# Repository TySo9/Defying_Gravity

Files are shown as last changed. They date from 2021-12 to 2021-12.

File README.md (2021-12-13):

# Defying_Gravity
Repository for University Kentucky Senior Capstone Design Team (Spring/Fall 2021), Defying Gravity.

## iOS App
  - Written in C# for potential multi-platform support in the future
  - Designed for iPad
  - Controls the ESP32 via Wi-Fi
  
## ESP32
  - Written in Arduino C
  - Controls motors, sensors, etc on the platform
  - Controlled by iOS App via Wi-Fi

## 3D Drawings
  - Files for the 3D printed parts of the device
     - Left Brake "Pads"
     - Right Brake "Pads"
     - Washer (?)

## 3D Drawings (KiCAD)
  - Files for PCB

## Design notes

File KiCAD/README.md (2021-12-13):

PCB Design Files for KiCAD

Because we decided to build a perfboard based on the Schematic for time, testing, and budget purposes, the PCB itself is unfinished. The Schematic, Ratnest, Part Selection, Footprint Design/Selection, etc.. is all finished. Since all the groundwork is complete, all the next person has to do is move around the footprints, connect the ratnest, and generate Gerbers. Should be quick and easy. I recommend using PCBWay to fabricate the boards.

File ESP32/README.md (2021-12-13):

To upload the code to an ESP32 using Arduino IDE, follow these instructions:
    https://randomnerdtutorials.com/installing-the-esp32-board-in-arduino-ide-windows-instructions/
    
    - Because Arduino does not know how to deal with nested folders, make sure all .h and .cpp library files you are using are put inside the same folder as the            main sketch Defying_Gravity_Main.ino
    
To upload the code to an ESP32 using Visual Studio Code, follow these instructions:
    https://randomnerdtutorials.com/vs-code-platformio-ide-esp32-esp8266-arduino/

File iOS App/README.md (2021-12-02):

At the current moment, I don't know how to add upload the code effectively to this but link to the gitbub with the code: https://github.com/lroberts7952/SlipNTrip

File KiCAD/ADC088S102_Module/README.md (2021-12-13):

PCB Design for an ADC module, can be used to attach to breakboard or perfbpard

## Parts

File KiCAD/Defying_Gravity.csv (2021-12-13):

Reference | Value | Footprint | Datasheet | MANUFACTURER | PARTREV
U1 | ESP32-DEVKITC-32D | _Defying_Gravity_Parts:MODULE_ESP32-DEVKITC-32D | https://www.espressif.com/sites/default/files/documentation/esp32-wroom-32_datasheet_en.pdf | Espressif Systems | 4
J4 | E-STOP (inverted) |  | ~
J5 | BRAKES POWER |  | ~
J3 | BUCK CONVERTER |  | ~
R12 | 0 Ω | Resistor_SMD:R_0805_2012Metric_Pad1.20x1.40mm_HandSolder | ~
R11 | 0 Ω | Resistor_SMD:R_0805_2012Metric_Pad1.20x1.40mm_HandSolder | ~
J12 | VESC 2 |  | ~
J11 | VESC 1 |  | ~
D1 | 1N5408 | Diode_THT:D_DO-201AD_P15.24mm_Horizontal | http://www.vishay.com/docs/88516/1n5400.pdf
Q1 | IRLB8721PBF | Package_TO_SOT_THT:TO-220-3_Vertical | http://www.infineon.com/dgdl/irlb8721pbf.pdf?fileId=5546d462533600a40153566056732591
C22 | 0.1 uF | Capacitor_SMD:C_0805_2012Metric_Pad1.18x1.45mm_HandSolder | ~
R3 | 51Ω | Resistor_SMD:R_0805_2012Metric_Pad1.20x1.40mm_HandSolder | ~
C12 | 1 uF | Capacitor_SMD:C_0805_2012Metric_Pad1.18x1.45mm_HandSolder | ~
R13 | 0 Ω | Resistor_SMD:R_0805_2012Metric_Pad1.20x1.40mm_HandSolder | ~
U2 | LP2950-3.0_TO92 | Package_TO_SOT_THT:TO-92_Inline | http://www.ti.com/lit/ds/symlink/lp2950-n.pdf
C11 | 1 uF | Capacitor_SMD:C_0805_2012Metric_Pad1.18x1.45mm_HandSolder | ~
C21 | 0.1 uF | Capacitor_SMD:C_0805_2012Metric_Pad1.18x1.45mm_HandSolder | ~
C4 | 1 uF | Capacitor_SMD:C_0805_2012Metric_Pad1.18x1.45mm_HandSolder | ~
C23 | 0.1 uF | Capacitor_SMD:C_0805_2012Metric_Pad1.18x1.45mm_HandSolder | ~
C312 | 1nF | Capacitor_SMD:C_0805_2012Metric_Pad1.18x1.45mm_HandSolder | ~
R212 | 22Ω | Resistor_SMD:R_0805_2012Metric_Pad1.20x1.40mm_HandSolder | ~
C313 | 1nF | Capacitor_SMD:C_0805_2012Metric_Pad1.18x1.45mm_HandSolder | ~
R213 | 22Ω | Resistor_SMD:R_0805_2012Metric_Pad1.20x1.40mm_HandSolder | ~
J22 | PRESSURE SENSOR GRID | _Defying_Gravity_Parts:M50-3550642 | ~
C314 | 1nF | Capacitor_SMD:C_0805_2012Metric_Pad1.18x1.45mm_HandSolder | ~
R214 | 22Ω | Resistor_SMD:R_0805_2012Metric_Pad1.20x1.40mm_HandSolder | ~
C315 | 1nF | Capacitor_SMD:C_0805_2012Metric_Pad1.18x1.45mm_HandSolder | ~
R215 | 22Ω | Resistor_SMD:R_0805_2012Metric_Pad1.20x1.40mm_HandSolder | ~
C316 | 1nF | Capacitor_SMD:C_0805_2012Metric_Pad1.18x1.45mm_HandSolder | ~
R216 | 22Ω | Resistor_SMD:R_0805_2012Metric_Pad1.20x1.40mm_HandSolder | ~
C317 | 1nF | Capacitor_SMD:C_0805_2012Metric_Pad1.18x1.45mm_HandSolder | ~
R217 | 22Ω | Resistor_SMD:R_0805_2012Metric_Pad1.20x1.40mm_HandSolder | ~
C318 | 1nF | Capacitor_SMD:C_0805_2012Metric_Pad1.18x1.45mm_HandSolder | ~
R218 | 22Ω | Resistor_SMD:R_0805_2012Metric_Pad1.20x1.40mm_HandSolder | ~
C319 | 1nF | Capacitor_SMD:C_0805_2012Metric_Pad1.18x1.45mm_HandSolder | ~
R219 | 22Ω | Resistor_SMD:R_0805_2012Metric_Pad1.20x1.40mm_HandSolder | ~
C320 | 1nF | Capacitor_SMD:C_0805_2012Metric_Pad1.18x1.45mm_HandSolder | ~
R220 | 22Ω | Resistor_SMD:R_0805_2012Metric_Pad1.20x1.40mm_HandSolder | ~
C321 | 1nF | Capacitor_SMD:C_0805_2012Metric_Pad1.18x1.45mm_HandSolder | ~
R221 | 22Ω | Resistor_SMD:R_0805_2012Metric_Pad1.20x1.40mm_HandSolder | ~
C322 | 1nF | Capacitor_SMD:C_0805_2012Metric_Pad1.18x1.45mm_HandSolder | ~
R222 | 22Ω | Resistor_SMD:R_0805_2012Metric_Pad1.20x1.40mm_HandSolder | ~
C31 | 1nF | Capacitor_SMD:C_0805_2012Metric_Pad1.18x1.45mm_HandSolder | ~
C32 | 1nF | Capacitor_SMD:C_0805_2012Metric_Pad1.18x1.45mm_HandSolder | ~
J21 | PRESSURE SENSOR GIRD w/ power | _Defying_Gravity_Parts:M50-3550642 | ~
C33 | 1nF | Capacitor_SMD:C_0805_2012Metric_Pad1.18x1.45mm_HandSolder | ~
R23 | 22Ω | Resistor_SMD:R_0805_2012Metric_Pad1.20x1.40mm_HandSolder | ~
C34 | 1nF | Capacitor_SMD:C_0805_2012Metric_Pad1.18x1.45mm_HandSolder | ~
R24 | 22Ω | Resistor_SMD:R_0805_2012Metric_Pad1.20x1.40mm_HandSolder | ~
C35 | 1nF | Capacitor_SMD:C_0805_2012Metric_Pad1.18x1.45mm_HandSolder | ~
R25 | 22Ω | Resistor_SMD:R_0805_2012Metric_Pad1.20x1.40mm_HandSolder | ~
C36 | 1nF | Capacitor_SMD:C_0805_2012Metric_Pad1.18x1.45mm_HandSolder | ~
R26 | 22Ω | Resistor_SMD:R_0805_2012Metric_Pad1.20x1.40mm_HandSolder | ~
C37 | 1nF | Capacitor_SMD:C_0805_2012Metric_Pad1.18x1.45mm_HandSolder | ~
R27 | 22Ω | Resistor_SMD:R_0805_2012Metric_Pad1.20x1.40mm_HandSolder | ~
C38 | 1nF | Capacitor_SMD:C_0805_2012Metric_Pad1.18x1.45mm_HandSolder | ~
R28 | 22Ω | Resistor_SMD:R_0805_2012Metric_Pad1.20x1.40mm_HandSolder | ~
C39 | 1nF | Capacitor_SMD:C_0805_2012Metric_Pad1.18x1.45mm_HandSolder | ~
R29 | 22Ω | Resistor_SMD:R_0805_2012Metric_Pad1.20x1.40mm_HandSolder | ~
C310 | 1nF | Capacitor_SMD:C_0805_2012Metric_Pad1.18x1.45mm_HandSolder | ~
R210 | 22Ω | Resistor_SMD:R_0805_2012Metric_Pad1.20x1.40mm_HandSolder | ~
C311 | 1nF | Capacitor_SMD:C_0805_2012Metric_Pad1.18x1.45mm_HandSolder | ~
R211 | 22Ω | Resistor_SMD:R_0805_2012Metric_Pad1.20x1.40mm_HandSolder | ~
R22 | 22Ω | Resistor_SMD:R_0805_2012Metric_Pad1.20x1.40mm_HandSolder | ~
R21 | 22Ω | Resistor_SMD:R_0805_2012Metric_Pad1.20x1.40mm_HandSolder | ~
U33 | ADC088S102CIMT_NOPB | _Defying_Gravity_Parts:ADC088S102CIMT&slash_NOPB | https://www.ti.com/lit/ds/symlink/adc088s102.pdf?HQS=dis-mous-null-mousermode-dsf-pf-null-wwe&ts=1635440733857
U32 | ADC088S102CIMT_NOPB | _Defying_Gravity_Parts:ADC088S102CIMT&slash_NOPB | https://www.ti.com/lit/ds/symlink/adc088s102.pdf?HQS=dis-mous-null-mousermode-dsf-pf-null-wwe&ts=1635440733857
U31 | ADC088S102CIMT_NOPB | _Defying_Gravity_Parts:ADC088S102CIMT&slash_NOPB | https://www.ti.com/lit/ds/symlink/adc088s102.pdf?HQS=dis-mous-null-mousermode-dsf-pf-null-wwe&ts=1635440733857

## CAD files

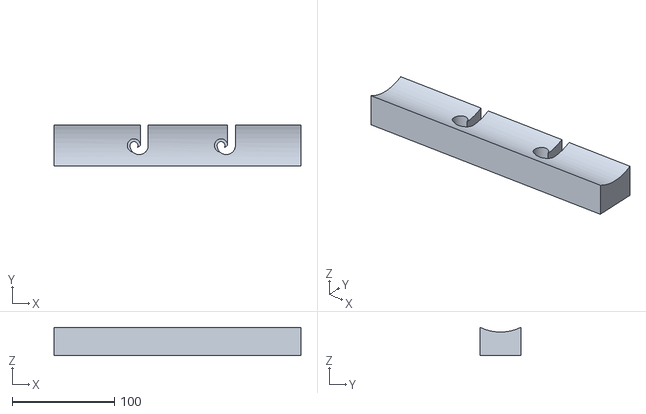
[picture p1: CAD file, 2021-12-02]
3D Drawings/Left Brake Pad (1).stl
241.3 x 40.0 x 27.8

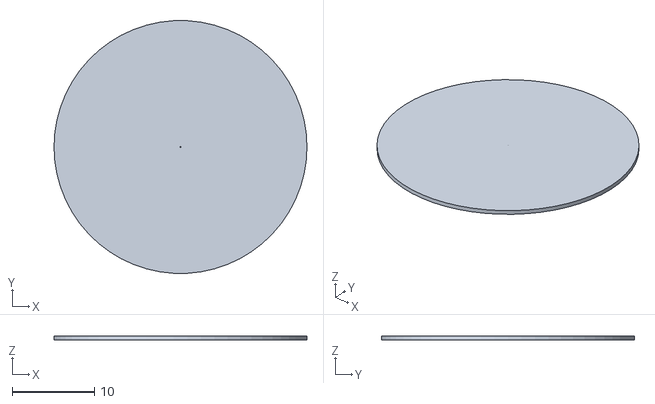
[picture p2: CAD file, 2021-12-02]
3D Drawings/Washer (1).stl
30.8 x 30.8 x 0.5

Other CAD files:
3D Drawings/Right Brake Pad.stl

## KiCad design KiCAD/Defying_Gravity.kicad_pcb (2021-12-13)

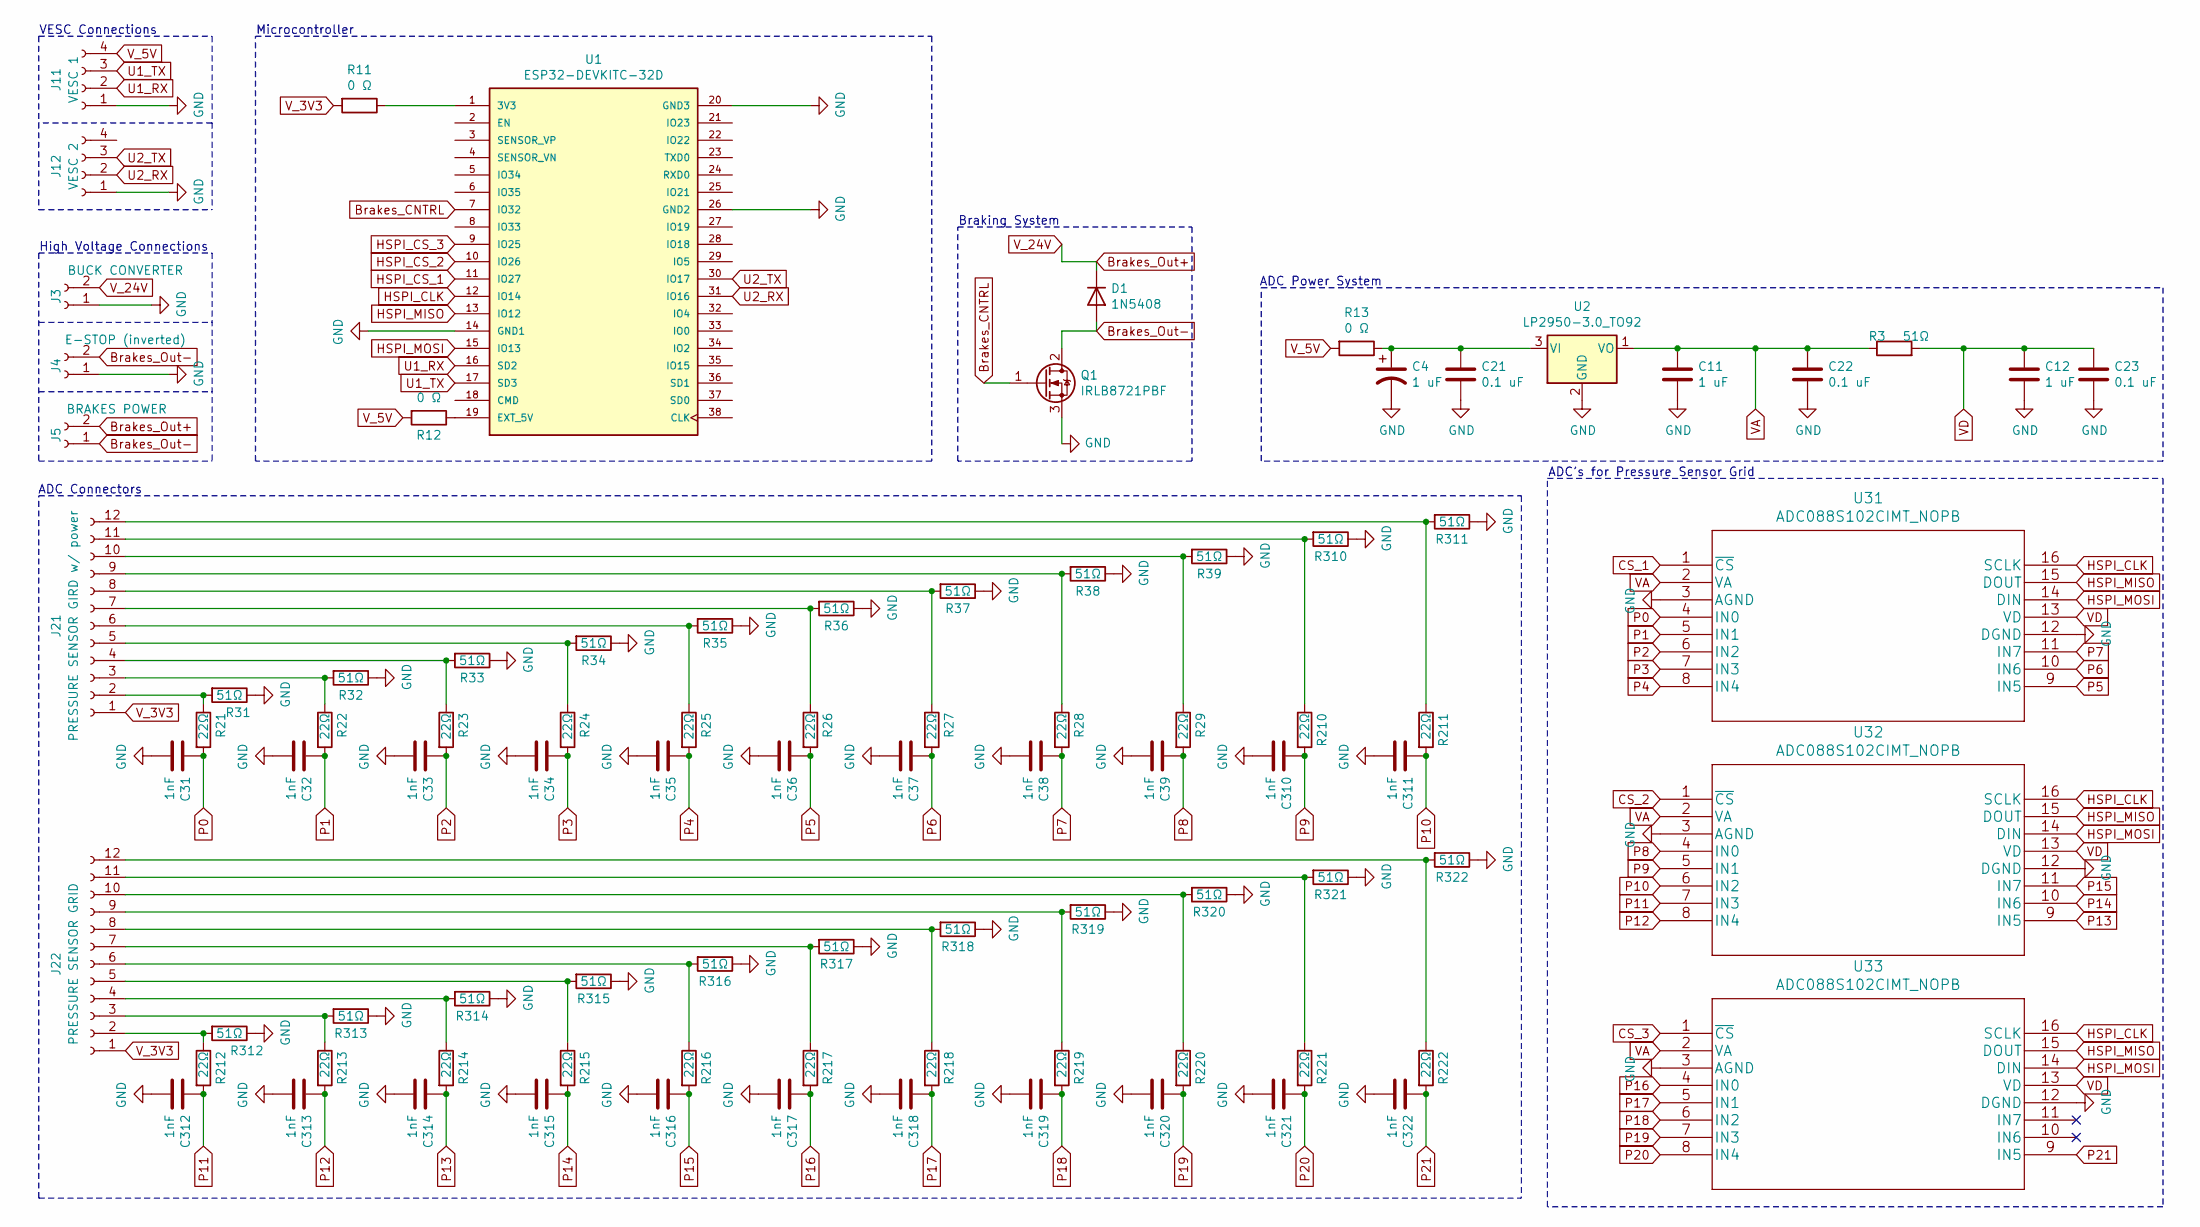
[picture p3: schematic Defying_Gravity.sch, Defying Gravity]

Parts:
C4, C11, C12: 1 uF; C_0805_2012Metric_Pad1.18x1.45mm_HandSolder
C21, C22, C23: 0.1 uF; C_0805_2012Metric_Pad1.18x1.45mm_HandSolder
C31, C32, C33, C34, C35, C36, C37, C38, C39, C310, C311, C312, C313, C314, C315, C316, C317, C318, C319, C320, C321, C322: 1nF; C_0805_2012Metric_Pad1.18x1.45mm_HandSolder
D1: 1N5408; D_DO-201AD_P15.24mm_Horizontal
J3: BUCK CONVERTER; TerminalBlock_Altech_AK300-2_P5.00mm
J4: E-STOP (inverted); TerminalBlock_Altech_AK300-2_P5.00mm
J5: BRAKES POWER; TerminalBlock_Altech_AK300-2_P5.00mm
J11: VESC 1; PinHeader_1x04_P2.54mm_Vertical
J12: VESC 2; PinHeader_1x04_P2.54mm_Vertical
J21: PRESSURE SENSOR GIRD w/ power; M50-3550642
J22: PRESSURE SENSOR GRID; M50-3550642
Q1: IRLB8721PBF; TO-220-3_Vertical
R3, R31, R32, R33, R34, R35, R36, R37, R38, R39, R310, R311, R312, R313, R314, R315, R316, R317, R318, R319, R320, R321, R322: 51Ω; R_0805_2012Metric_Pad1.20x1.40mm_HandSolder
R11, R12, R13: 0 Ω; R_0805_2012Metric_Pad1.20x1.40mm_HandSolder
R21, R22, R23, R24, R25, R26, R27, R28, R29, R210, R211, R212, R213, R214, R215, R216, R217, R218, R219, R220, R221, R222: 22Ω; R_0805_2012Metric_Pad1.20x1.40mm_HandSolder
U1: ESP32-DEVKITC-32D; MODULE_ESP32-DEVKITC-32D; PARTREV 4
U2: LP2950-3.0_TO92; TO-92_Inline
U31, U32, U33: ADC088S102CIMT_NOPB; ADC088S102CIMT&slash_NOPB

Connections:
Brakes_CNTRL: Q1.1 (G), U1.7 (IO32)
Brakes_Out+: D1.1 (K), J3.2, J5.2
Brakes_Out-: D1.2 (A), J4.2, J5.1, Q1.2 (D)
CS_1: U31.1 (~CS)
CS_2: U32.1 (~CS)
CS_3: U33.1 (~CS)
GND: C4.2, C11.2, C12.2, C21.2, C22.2, C23.2, C31.2, C32.2, C33.2, C34.2, C35.2, C36.2, C37.2, C38.2, C39.2, C310.2, C311.2, C312.2, C313.2, C314.2, C315.2, C316.2, C317.2, C318.2, C319.2, C320.2, C321.2, C322.2, J3.1, J4.1, J11.1, J12.1, Q1.3 (S), R31.1, R32.1, R33.1, R34.1, R35.1, R36.1, R37.1, R38.1, R39.1, R310.1, R311.1, R312.1, R313.1, R314.1, R315.1, R316.1, R317.1, R318.1, R319.1, R320.1, R321.1, R322.1, U1.14 (GND1), U1.20 (GND3), U1.26 (GND2), U2.2 (GND), U31.3 (AGND), U31.12 (DGND), U32.3 (AGND), U32.12 (DGND), U33.3 (AGND), U33.12 (DGND)
HSPI_CLK: U1.12 (IO14), U31.16 (SCLK), U32.16 (SCLK), U33.16 (SCLK)
HSPI_CS_1: U1.11 (IO27)
HSPI_CS_2: U1.10 (IO26)
HSPI_CS_3: U1.9 (IO25)
HSPI_MISO: U1.13 (IO12), U31.15 (DOUT), U32.15 (DOUT), U33.15 (DOUT)
HSPI_MOSI: U1.15 (IO13), U31.14 (DIN), U32.14 (DIN), U33.14 (DIN)
unnamed: C4.1, C21.1, R13.1, U2.3 (VI)
unnamed: J21.2, R21.1, R31.2
unnamed: J21.3, R22.1, R32.2
unnamed: J21.4, R23.1, R33.2
unnamed: J21.5, R24.1, R34.2
unnamed: J21.6, R25.1, R35.2
unnamed: J21.7, R26.1, R36.2
unnamed: J21.8, R27.1, R37.2
unnamed: J21.9, R28.1, R38.2
unnamed: J21.10, R29.1, R39.2
unnamed: J21.11, R210.1, R310.2
unnamed: J21.12, R211.1, R311.2
unnamed: J22.2, R212.1, R312.2
unnamed: J22.3, R213.1, R313.2
unnamed: J22.4, R214.1, R314.2
unnamed: J22.5, R215.1, R315.2
unnamed: J22.6, R216.1, R316.2
unnamed: J22.7, R217.1, R317.2
unnamed: J22.8, R218.1, R318.2
unnamed: J22.9, R219.1, R319.2
unnamed: J22.10, R220.1, R320.2
unnamed: J22.11, R221.1, R321.2
unnamed: J22.12, R222.1, R322.2
unnamed: R11.1, U1.1 (3V3)
unnamed: R12.1, U1.19 (EXT_5V)
P0: C31.1, R21.2, U31.4 (IN0)
P1: C32.1, R22.2, U31.5 (IN1)
P2: C33.1, R23.2, U31.6 (IN2)
P3: C34.1, R24.2, U31.7 (IN3)
P4: C35.1, R25.2, U31.8 (IN4)
P5: C36.1, R26.2, U31.9 (IN5)
P6: C37.1, R27.2, U31.10 (IN6)
P7: C38.1, R28.2, U31.11 (IN7)
P8: C39.1, R29.2, U32.4 (IN0)
P9: C310.1, R210.2, U32.5 (IN1)
P10: C311.1, R211.2, U32.6 (IN2)
P11: C312.1, R212.2, U32.7 (IN3)
P12: C313.1, R213.2, U32.8 (IN4)
P13: C314.1, R214.2, U32.9 (IN5)
P14: C315.1, R215.2, U32.10 (IN6)
P15: C316.1, R216.2, U32.11 (IN7)
P16: C317.1, R217.2, U33.4 (IN0)
P17: C318.1, R218.2, U33.5 (IN1)
P18: C319.1, R219.2, U33.6 (IN2)
P19: C320.1, R220.2, U33.7 (IN3)
P20: C321.1, R221.2, U33.8 (IN4)
P21: C322.1, R222.2, U33.9 (IN5)
U1_RX: J11.2, U1.16 (SD2)
U1_TX: J11.3, U1.17 (SD3)
U2_RX: J12.2, U1.31 (IO16)
U2_TX: J12.3, U1.30 (IO17)
VA: C11.1, C22.1, R3.1, U2.1 (VO), U31.2 (VA), U32.2 (VA), U33.2 (VA)
VD: C12.1, C23.1, R3.2, U31.13 (VD), U32.13 (VD), U33.13 (VD)
V_3V3: J21.1, J22.1, R11.2
V_5V: J11.4, R12.2, R13.2

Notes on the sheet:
VESC Connections
Microcontroller
High Voltage Connections
Braking System
ADC Power System
ADC Connectors
ADC’s for Pressure Sensor Grid

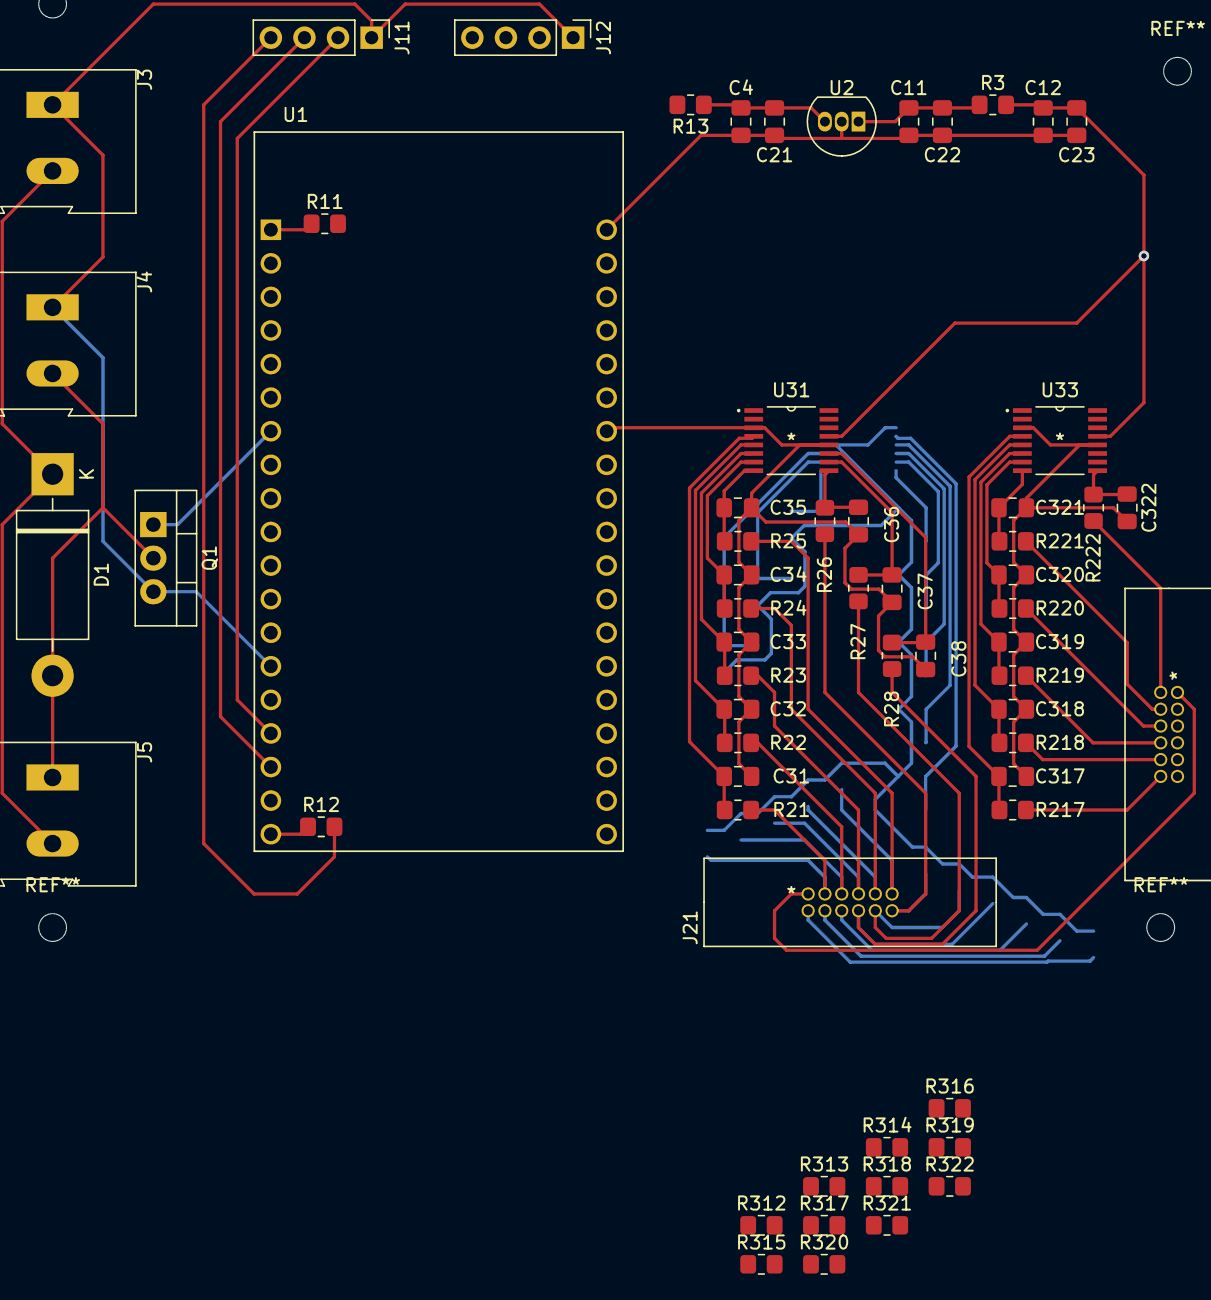
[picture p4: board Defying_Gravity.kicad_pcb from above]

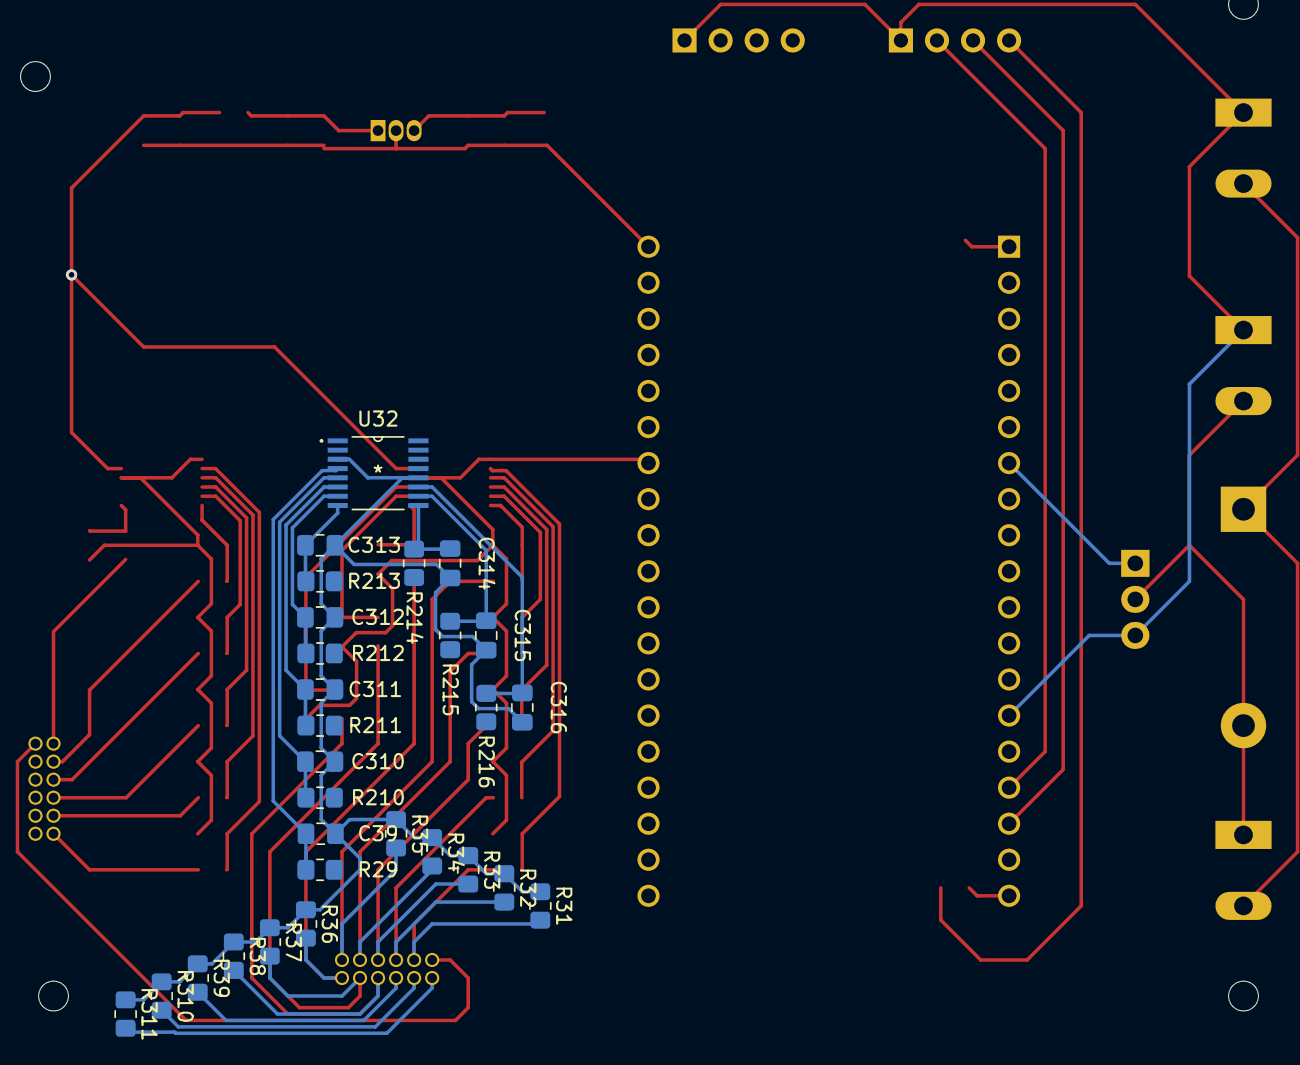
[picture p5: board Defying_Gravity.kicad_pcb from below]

Board: 2 copper layers, 90 parts (28 on the bottom side), 62 nets.

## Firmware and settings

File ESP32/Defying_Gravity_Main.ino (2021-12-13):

// @file :      Defying_Gravity_Main.ino
// Description: This code serves as the "brain" of the Defying Gravity: Slip and Trip Simulator Version 2, designed for EE 491 Senior Capstone Spring 2021
// Author:      Tyler Sovar
// Date:        11/28/2021

// -------------------------------------------------------------------------------------------
// WiFi Initiation | BEGIN |
// -------------------------------------------------------------------------------------------

// Load Wi-Fi library
#include <WiFi.h>
#include <WiFiUdp.h>

// Initialize UDP object
WiFiUDP UDP;

// WiFi Constants
const char* ssid     = "espWiFi";   // WiFi Name
const char* password = "123456789"; // Wifi Password
unsigned int localUdpPort = 4210;   // local port to listen on

// UDP Client Info
IPAddress client_IP;
unsigned int client_Port;
bool UDP_connected;

// -------------------------------------------------------------------------------------------
// WiFi Initiation | END |
// -------------------------------------------------------------------------------------------

// -------------------------------------------------------------------------------------------
// ADC Initiation | BEGIN |
// -------------------------------------------------------------------------------------------

// Load ADC Library
//#include "ADC088S102.h" //OLD ADCs (burned up, changed to meet deadlines)
#include "MCP3008.h"

// ADC Objects
// Change depending on which ADCs are being used
//ADC088S102 ADC_1;
//ADC088S102 ADC_2;
//ADC088S102 ADC_3;
MCP3008 ADC_1;
MCP3008 ADC_2;
MCP3008 ADC_3;


// SPI Chip Select pins
#define CS_1  27
#define CS_2  26
#define CS_3  25

const int EDGES = 11;
const int THRESHOLD = 500;  // 51 Ohm

// -------------------------------------------------------------------------------------------
// ADC Initiation | END |
// -------------------------------------------------------------------------------------------

// -------------------------------------------------------------------------------------------
// VESC Control Initiation | BEGIN |
// -------------------------------------------------------------------------------------------

// Code from SolidGeek on GitHub, as recommended by Flipsky (vesc manufacturer)
// License in VescUart folder
#include "VescUart.h"

// Initialize VESC UART Object
VescUart UART_1;
VescUart UART_2;

String command;
float value;
int throttle = 127;

// SET UART Pins
#define U2_RX 16
#define U2_TX 17
#define U1_RX 9
#define U1_TX 10

// Brakes control pin
#define brakes_CNTRL 32

// -------------------------------------------------------------------------------------------
// VESC Control Initiation | END |
// -------------------------------------------------------------------------------------------

// Runs once at power on, initializes objects
void setup() {
  Serial.begin(115200);
  while(!Serial);

  init_wifi();
  
  init_ADCs();
  init_VESC();
  engage_brakes();

  delay(500);
  
}

// Main sketch code, runs on a loop until power off
void loop(){
  
  // Recieve UDP Message, convert to int
  String rcv = UDP_receive();
  int rotations = rcv.toInt();

  // Ensure that # of rotations is an acceptable number (too high will go too far, unsafe)
  if(rotations > 0 && rotations <= 60){
    
    // Send pre-perturbation foot location to iPad via UDP  
    send_surface();

    // Calculate tachometer steps to achieve desired number of rotations
    //    IMPORTANT: Use this once iPad is configureed to do so:   int mv = meters_to_tach(rotations);
    //        OR configure iPad to run this calculation
    int tach_steps = 60 * rotations;
    
    // Induce perturbation based on UDP input
    //    Currently set up to just customize distance
    //    Need to also change force, determine force characteristics in VescTool program
    motor_burst(220, tach_steps, false);
    
    // Send post-perturbation foot location to iPad via UDP  
    send_surface();
  }

  // Print foot location on serial line
  //    Remove when iPad is ready to recieve foot location data via UDP
  print_pressure_grid();

  delay(250);
}

// Unfinished code to parse a UDP recieved string into "command:int" to ensure correct behavior
// Possibly unneccessary if iPad app follows particular UDP send/recive sequence, leaving just in case
void get_UDP_cmd() {
  String rcv = UDP_receive();
  if( rcv != "" ) {
    int colon_index = rcv.indexOf(':');
    if(colon_index >= 0 ) {
      String command = rcv.substring(0, colon_index);
      if( command == "move") {
        int comma_index = rcv.indexOf(',');
        int first_value = rcv.substring(colon_index + 1, comma_index).toInt();
        int second_value = rcv.substring(colon_index + 1).toInt();
      }
    }
  }
  delay(500);
}



// -------------------------------------------------------------------------------------------
// iPad Communication | BEGIN |
// -------------------------------------------------------------------------------------------

void init_wifi() {

  // Set up offline WiFi output
  //    Pretends to be a router
  Serial.print("Setting soft-AP ... ");
  // WIFI INIT FORMAT:  WiFi.softAP(ssid, psk, channel, hidden, max_connection)
  Serial.println(WiFi.softAP(ssid, password) ? "Ready" : "Failed!");

  Serial.print("Soft-AP IP address = ");
  Serial.println(WiFi.softAPIP());

  delay(250);
  
  // Begin UDP
  UDP.begin(localUdpPort);
  Serial.printf("Now listening at IP %s, UDP port %d\n", WiFi.localIP().toString().c_str(), localUdpPort);
}


// Get UDP message, return as String
//    Bug: String appears to have a space newline at the end of the String, causes issues with comparing expected strings
//          - Was not a problem when converting to int, only worry about fixing if using "command:int" method
String UDP_receive(){
  
  char incomingPacket[255];   // Buffer for incoming packets
  
  // Wait until data is available, then read the packet
  int packetSize = UDP.parsePacket();
  if (packetSize)
  {
    // Receive incoming UDP packets
    Serial.printf("Received %d bytes from %s, port %d\n", packetSize, UDP.remoteIP().toString().c_str(), UDP.remotePort());
    
    int len = UDP.read(incomingPacket, 255);
    if (len > 0)
    {
      incomingPacket[len] = '\0';
    }
    Serial.printf("UDP packet contents: %s\n", incomingPacket);
    String msg(incomingPacket);
    
    return msg;
  }

  return "";
}

// Send message over UDP
void UDP_send(char msg[], IPAddress client_IP = UDP.remoteIP(), unsigned int client_port = localUdpPort) {
  
  // send back a reply, to the IP address and port we got the packet from
  UDP.beginPacket(client_IP, client_port);
  
  Serial.printf("Begin reply back to %s, port %d\n", client_IP.toString().c_str(), client_port);
  for(int i=0; i<strlen(msg); i++){
    Serial.print(msg[i]);
    UDP.write(msg[i]);
  }
  Serial.println("\nEnd reply...");
  UDP.endPacket();
}

// Check iPad connection/IP/port via broadcast, unfinished
//    Possibly unneccessary since iPad will be the only device on network
//    Was not neccessary at this point in the project, leaving code in case it is neccessary in the future
bool UDP_check(){
  
  // Send broadcast
  IPAddress broadcast_ip(255, 255, 255, 255);
  UDP_send("Hello?", broadcast_ip, localUdpPort);
  
  // Listen for return
  String returned_msg;
  //int t_i = millis();
  while(returned_msg != "Here!"){
    returned_msg = UDP_receive();
//    int t_f = millis();
//    if(t_f - t_i >= 30000){
//      return false;
//    }
  }
  
  // Check return validity, gather client data
  //if (returned_msg == "Here!"){
    //client_IP = UDP.remoteIP();
    //client_Port = UDP.remotePort();

    Serial.printf("Connected to %s, port %d\n", client_IP.toString().c_str(), client_Port);

    //return true;
  //}

  //return false;
  return true;
}

// -------------------------------------------------------------------------------------------
// iPad Communication | END |
// -------------------------------------------------------------------------------------------


// -------------------------------------------------------------------------------------------
// Pressure Sensor | BEGIN |
// -------------------------------------------------------------------------------------------

// Initialize ADC objects using predetermined pinout (at top of code)
void init_ADCs() {
  ADC_1.begin(CS_1);
  ADC_2.begin(CS_2);
  ADC_3.begin(CS_3);
}

// Print pressure grid to Serial (USB connection)
void print_pressure_grid(){
  int adc_Y[EDGES];
  int adc_X[EDGES];

  bool grid[EDGES+1][EDGES+1] = { false };

  // Y-Axis of pressure grid
  // First ADC
  adc_X[0]  = ADC_1.readADC(0);
  adc_X[1]  = ADC_1.readADC(1);
  adc_X[2]  = ADC_1.readADC(2);
  adc_X[3]  = ADC_1.readADC(3);
  adc_X[4]  = ADC_1.readADC(4);
  adc_X[5]  = ADC_1.readADC(5);
  adc_X[6]  = ADC_1.readADC(6);
  adc_X[7]  = ADC_1.readADC(7);
  // Second ADC
  adc_X[8]  = ADC_2.readADC(0);
  adc_X[9]  = ADC_2.readADC(1);
  adc_X[10] = ADC_2.readADC(2);

  // Y-Axis of pressure grid
  // Second ADC
  adc_Y[0]  = ADC_2.readADC(3);
  adc_Y[1]  = ADC_2.readADC(4);
  adc_Y[2]  = ADC_2.readADC(5);
  adc_Y[3]  = ADC_2.readADC(6);
  adc_Y[4]  = ADC_2.readADC(7);
  // Third ADC
  adc_Y[5]  = ADC_3.readADC(0);
  adc_Y[6]  = ADC_3.readADC(1);
  adc_Y[7]  = ADC_3.readADC(2);
  adc_Y[8]  = ADC_3.readADC(3);
  adc_Y[9]  = ADC_3.readADC(4);
  adc_Y[10] = ADC_3.readADC(5);


  // "Battleship" method for finding foot location
  // TODO: fix "ghosting" issue caused by diagonal foot locations using "cluster" sizes of trigger intersections based on patient foot size
  for( int i = 0; i < EDGES; i++ ){
    for( int j = 0; j < EDGES; j++ ){
      if( (adc_Y[i] >= THRESHOLD) && (adc_X[j] >= THRESHOLD) ){
        grid[i][j] = true;
      }
      else{
        grid[i][j] = false;
      }
    }
  }

  Serial.print(" -------------------------------------------");
  Serial.println();

  // Print boolean grid to show "X" where foot is present
  for( int i = 0; i < EDGES; i++ ){
    Serial.print("|");
     for( int j = EDGES-1; j >= 0; j-- ){
        if( grid[i][j] ){
          Serial.print(" X |");
        }
        else{
          Serial.print("   |");
        }
     }
     Serial.println();
     Serial.println(" -------------------------------------------");
  }
}

// Send pressure grid over UDP
// Never got to test since iPad app wasn't ready. Should work, but do testing before assuming no bugs.
// UDP Message Format Example: "<time>;adc_x[0], adc_x[1]; adc_y[0], adc_y[1];"
void send_surface(){
  int adc_Y[EDGES];
  int adc_X[EDGES];
  int grid[EDGES][EDGES];
  String kinda_csv = "";

  unsigned long t = millis();
  kinda_csv += String(t) + ";";

  // Y-Axis of pressure grid
  // First ADC
  adc_X[0]  = ADC_1.readADC(0);
  adc_X[1]  = ADC_1.readADC(1);
  adc_X[2]  = ADC_1.readADC(2);
  adc_X[3]  = ADC_1.readADC(3);
  adc_X[4]  = ADC_1.readADC(4);
  adc_X[5]  = ADC_1.readADC(5);
  adc_X[6]  = ADC_1.readADC(6);
  adc_X[7]  = ADC_1.readADC(7);
  // Second ADC
  adc_X[8]  = ADC_2.readADC(0);
  adc_X[9]  = ADC_2.readADC(1);
  adc_X[10] = ADC_2.readADC(2);

  // Y-Axis of pressure grid
  // Second ADC
  adc_Y[0]  = ADC_2.readADC(3);
  adc_Y[1]  = ADC_2.readADC(4);
  adc_Y[2]  = ADC_2.readADC(5);
  adc_Y[3]  = ADC_2.readADC(6);
  adc_Y[4]  = ADC_2.readADC(7);
  // Third ADC
  adc_Y[5]  = ADC_3.readADC(0);
  adc_Y[6]  = ADC_3.readADC(1);
  adc_Y[7]  = ADC_3.readADC(2);
  adc_Y[8]  = ADC_3.readADC(3);
  adc_Y[9]  = ADC_3.readADC(4);
  adc_Y[10] = ADC_3.readADC(5);

  // Fill x-axis data 
  for( int i=0; i < EDGES; i++ ){
      kinda_csv += String(adc_X[i]) + ",";
  }
  kinda_csv += ";";

  // Fill y-axis data
  for( int i=0; i < EDGES; i++ ){
      kinda_csv += String(adc_Y[i]) + ",";
  }
  kinda_csv += ";";

  Serial.println("SENDING UDP:\t" + kinda_csv);
  char* c = strcpy(new char[kinda_csv.length() + 1], kinda_csv.c_str());
  UDP_send(c);
  
}

// -------------------------------------------------------------------------------------------
// Pressure Sensor | END |
// -------------------------------------------------------------------------------------------

// -------------------------------------------------------------------------------------------
// VESC Control | BEIGN |
// -------------------------------------------------------------------------------------------

// Initialize VESC Motor controllers
void init_VESC(){
  // Configure UART interfaces
  Serial1.begin(115200, SERIAL_8N1, U1_RX, U1_TX);
  Serial2.begin(115200, SERIAL_8N1, U2_RX, U2_TX);
  
  while (!Serial1) {;}
  while (!Serial2) {;}
  
  // Define which ports to use as UART
  UART_1.setSerialPort(&Serial1);
  UART_2.setSerialPort(&Serial2);

  // Initialize Brakes Control
  pinMode(brakes_CNTRL, OUTPUT);
  digitalWrite(brakes_CNTRL, HIGH);
  
  Serial.println("BEGIN VESC CONTROL...");
}

// Check if VESCs are connected via UART, print telemetry data for testing, fill bool array to verify connection elsewhere
bool VESC_connected[2] = {false, false};
void check_vescs(){
  if ( UART_1.getVescValues() ) {
      Serial.println("UART 1:------");
      Serial.println("RPM:\t" + String(UART_1.data.rpm));
      Serial.println("Voltage:\t" + String(UART_1.data.inpVoltage));
      Serial.println("Current:\t" + String(UART_1.data.ampHours));
      Serial.println("Tachometer:\t" + String(UART_1.data.tachometerAbs));
      VESC_connected[0] = true;
  }
  else
  {
    Serial.println("U1: Failed to get data!");

    VESC_connected[0] = false;
  }

  if ( UART_2.getVescValues() ) {
      Serial.println("UART 2:------");
      Serial.println("RPM:\t" + String(UART_2.data.rpm));
      Serial.println("Voltage:\t" + String(UART_2.data.inpVoltage));
      Serial.println("Current:\t" + String(UART_2.data.ampHours));
      Serial.println("Tachometer:\t" + String(UART_2.data.tachometerAbs));
      VESC_connected[1] = true;
  }
  else
  {
    Serial.println("U2: Failed to get data!");

    VESC_connected[1] = false;
  }
  delay(500);
}

// Engage solenoid brakes
void engage_brakes() { 
  Serial.println("ENGAGE BRAKES");
  digitalWrite(brakes_CNTRL, HIGH);
  return;
}

// Disengage solenoid brakes
void disengage_brakes() {
  Serial.println("DIS-ENGAGE BRAKES");
  digitalWrite(brakes_CNTRL, LOW);
  delay(500);
  return;
}

// Engage in-motor brakes sequence
void motor_stop() {
    // Move motors in reverse to brake
    UART_1.nunchuck.valueY = 0;
    UART_2.nunchuck.valueY = 0;
    UART_1.setNunchuckValues();
    UART_2.setNunchuckValues();

    // Change to make brake time longer or faster
    delay(2000);

    // Set motors to neutral
    UART_1.nunchuck.valueY = 127;
    UART_2.nunchuck.valueY = 127;
    UART_1.setNunchuckValues();
    UART_2.setNunchuckValues();
    
    Serial.println("STOPPED!");
}

// Convert meters to tachometer rotation values
int meters_to_tach(float meters){
  // Wheel diameter:  90 mm
  // Full Rotation:   282.743339 (wheel circumference) = 60 tachs
  // Conversion:      1 tach = 4.71239 mm, 
  //                  1 mm = 0.21220659 tachs
  //                  1 meter = 212.20659 tachs
  
  int wheel_d   = 90;
  int rot_tach  = 60;
  
  float rot_mm  = 3.14 * wheel_d;
  float conv    = (rot_tach/rot_mm) * 1000;

  // Round because Tachometer only deals with whole numbers
  int tach_steps = round(conv * meters);
  
  return tach_steps;
}

// Induce perturbation
void motor_burst(int throttle, int tach_steps, bool show_data) {

  // Ensure VESC connection, end if failed
  check_vescs();
  if( (VESC_connected[0] && VESC_connected[1]) == false ) {
    Serial.println("ERROR: NO VESCS CONNECTED");
    return;
  }
  else if ( VESC_connected[0] == false ) {
    Serial.println("ERROR: VESC 1 NOT CONNECTED");
    return;
  }
  else if ( VESC_connected[1] == false ) {
    Serial.println("ERROR: VESC 2 NOT CONNECTED");
    return;
  }

  // Turn off solenoid brakes before motor movement
  disengage_brakes();

  // Check throttle value
  //    127     = Neutral
  //    0-126   = Backwards, smaller is more force 
  //    128-255 = Forwards, larger is more force
  if ( throttle >= 0 && throttle <= 255) {
    
    // Get initial tachometer value to determine distance moved
    UART_1.getVescValues();
    int init_tach = UART_1.data.tachometerAbs;

    // Set motors to desired throttle (force)
    UART_1.nunchuck.valueY = throttle;
    UART_2.nunchuck.valueY = throttle;
    UART_1.setNunchuckValues();
    UART_2.setNunchuckValues();

    Serial.println(throttle);
    Serial.println("STARTED");
    
    int tach = 0;
    // Show data for troubleshooting if specified in function call
    if (show_data){ 
      // Loop until desired distance moved has been met
      while(tach <= init_tach + tach_steps)
      {
        // Get current tachometer value to be compared
        UART_1.getVescValues();
        tach = UART_1.data.tachometerAbs;

        // Print telemetry data
        Serial.println("RPM:\t" + String(UART_1.data.rpm));
        Serial.println("Voltage:\t" + String(UART_1.data.inpVoltage));
        Serial.println("Current:\t" + String(UART_1.data.ampHours));
        Serial.println("Tachometer:\t" + String(UART_1.data.tachometerAbs));

        // Software E-Stop
        if (UDP_receive().toInt() == -999){
          engage_brakes();
          motor_stop();
          break;
        }    
      }
    }
    
    // Normal operation
    else{
      // Loop until desired distance moved has been met
      while(tach <= init_tach + tach_steps)
      {
        // Get current tachometer value to be compared
        UART_1.getVescValues();
        tach = UART_1.data.tachometerAbs;

        // Software E-Stop
        if (UDP_receive().toInt() == -999){
          engage_brakes();
          motor_stop();
          break;
        }
      }
    }

    // Initiate stop sequence
    engage_brakes();  // Solenoid brakes
    motor_stop();     // In-motor brakes
  }

  // Account for user error to not send invalid UART data to VESCs
  else
  {
    Serial.println("Unvalid throttle value");
    engage_brakes();
    motor_stop(); 
  }
}

// -------------------------------------------------------------------------------------------
// VESC Control | END |
// -------------------------------------------------------------------------------------------

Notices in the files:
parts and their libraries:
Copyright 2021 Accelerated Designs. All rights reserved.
